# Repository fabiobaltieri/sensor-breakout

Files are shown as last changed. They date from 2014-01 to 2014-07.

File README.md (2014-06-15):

Sensor Breakout
===============

http://fabiobaltieri.com/2014/06/15/sensor-breakout/

This project is brekout board for prototyping wireless sensors.

Main features:
- ATMega88P microcontroller (can mount up to an ATMetga328)
- nRF24L01+ low power 2.4GHz radio
- On board Lithium battery charger and 3.3V regulator
- Dual mounting option for the USB port (micro B and A)
- Prototype area

License
-------

This program is free software: you can redistribute it and/or modify
it under the terms of the GNU General Public License as published by
the Free Software Foundation, either version 2 of the License, or
(at your option) any later version.

Contents
--------

    COPYING      text version of the GPL
    README       this file
    bootloader/  source directory for bootloader
    firmware/    source directory for main firmware
    hardware/    source directory for the hardware design

Firmware and Bootloader
-----------------------

Building requires an avr-gcc toolchain, in the firmware/ or bootloader/
directory, to build run:

    make

Flashing the firmware on the device requires avrdude and a compatible hardware
programmer. Default configuration is stored at the beginning of the Makefile.
To program with the default configuration, run:

    make flash

Fuses can be configured running:

    make fuses

To program the main firmware from the bootloader, use the command:

    make boot

Hardware
--------

All hardware files (schematic, layout and libraries) are in CadSoft Eagle
format.

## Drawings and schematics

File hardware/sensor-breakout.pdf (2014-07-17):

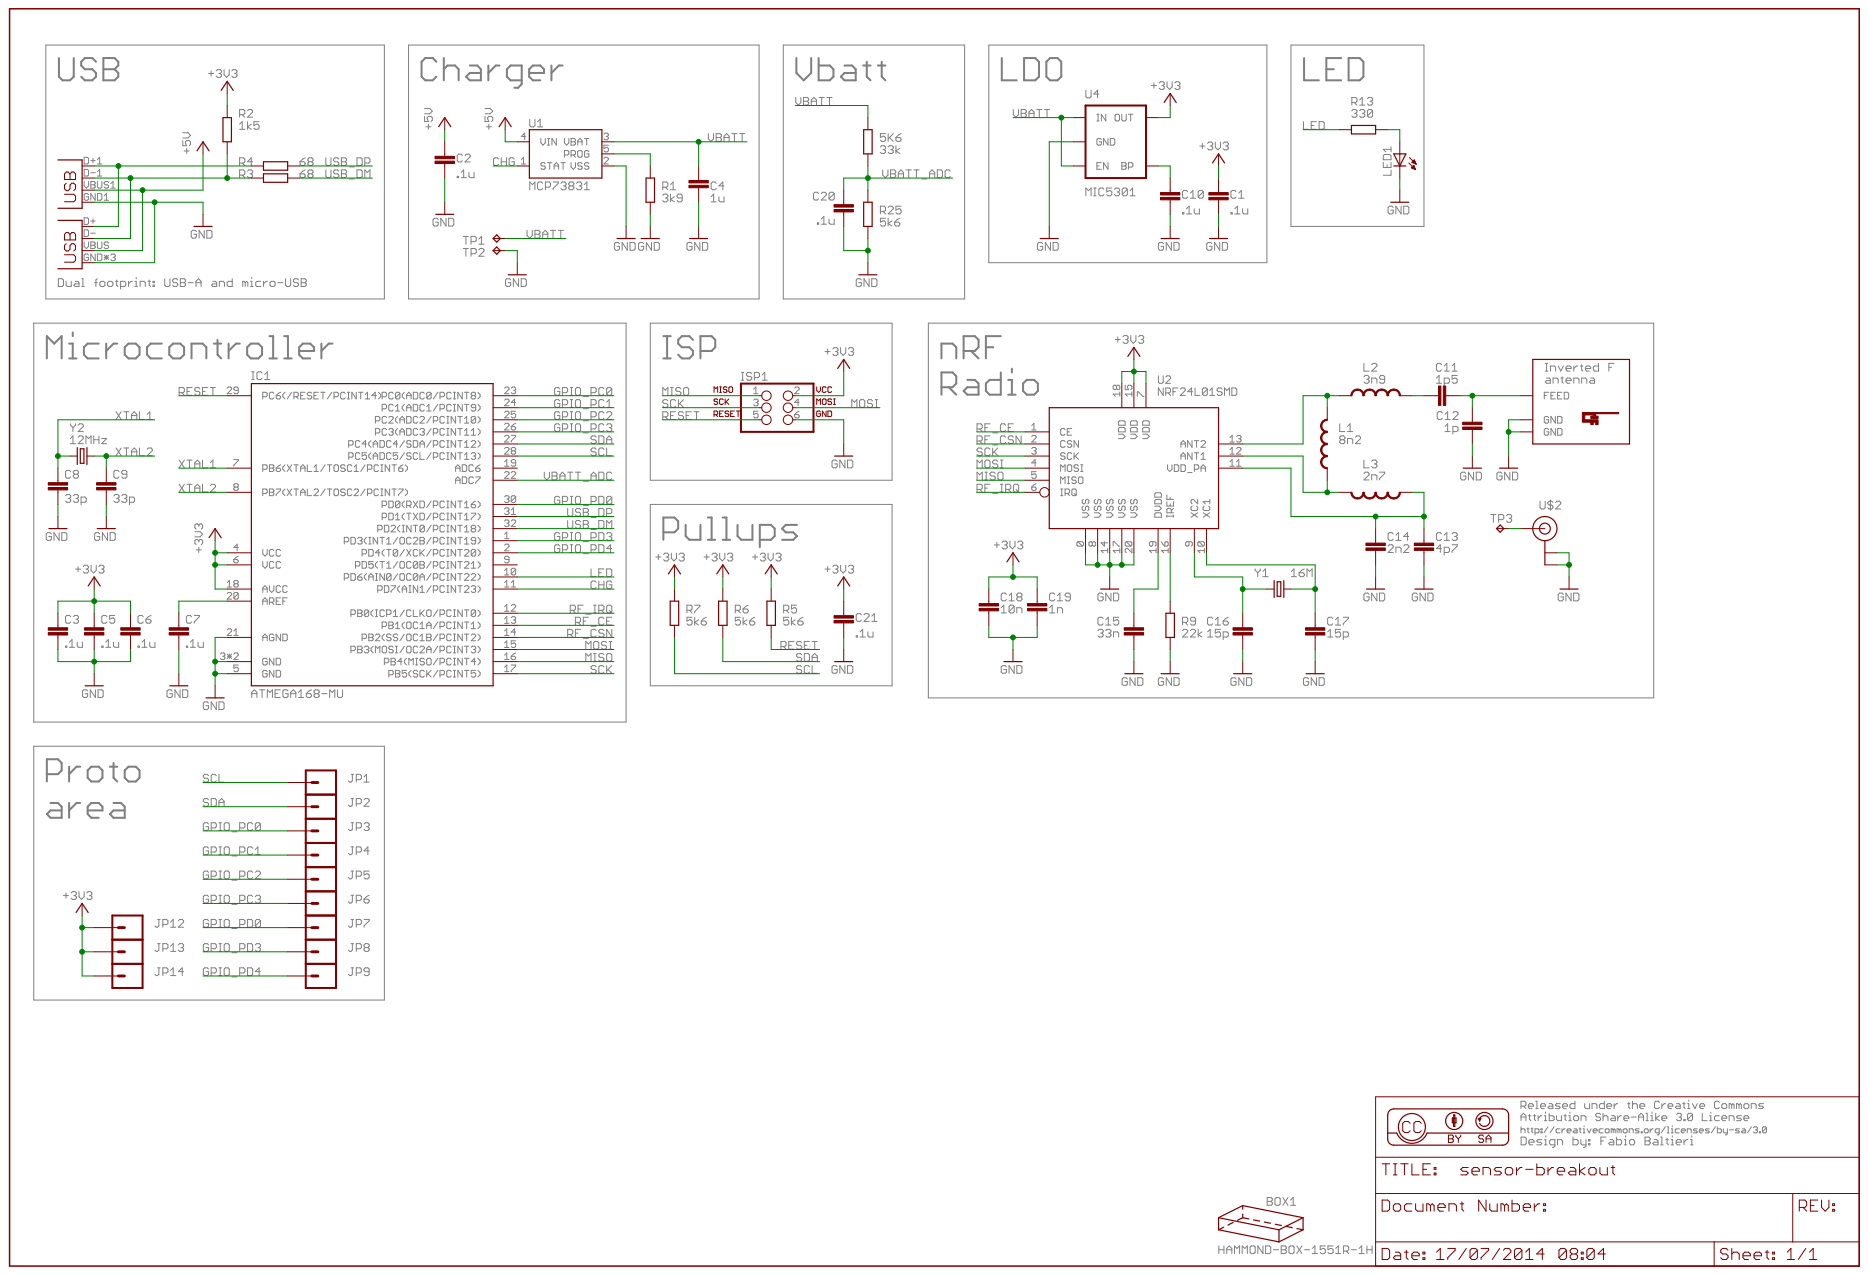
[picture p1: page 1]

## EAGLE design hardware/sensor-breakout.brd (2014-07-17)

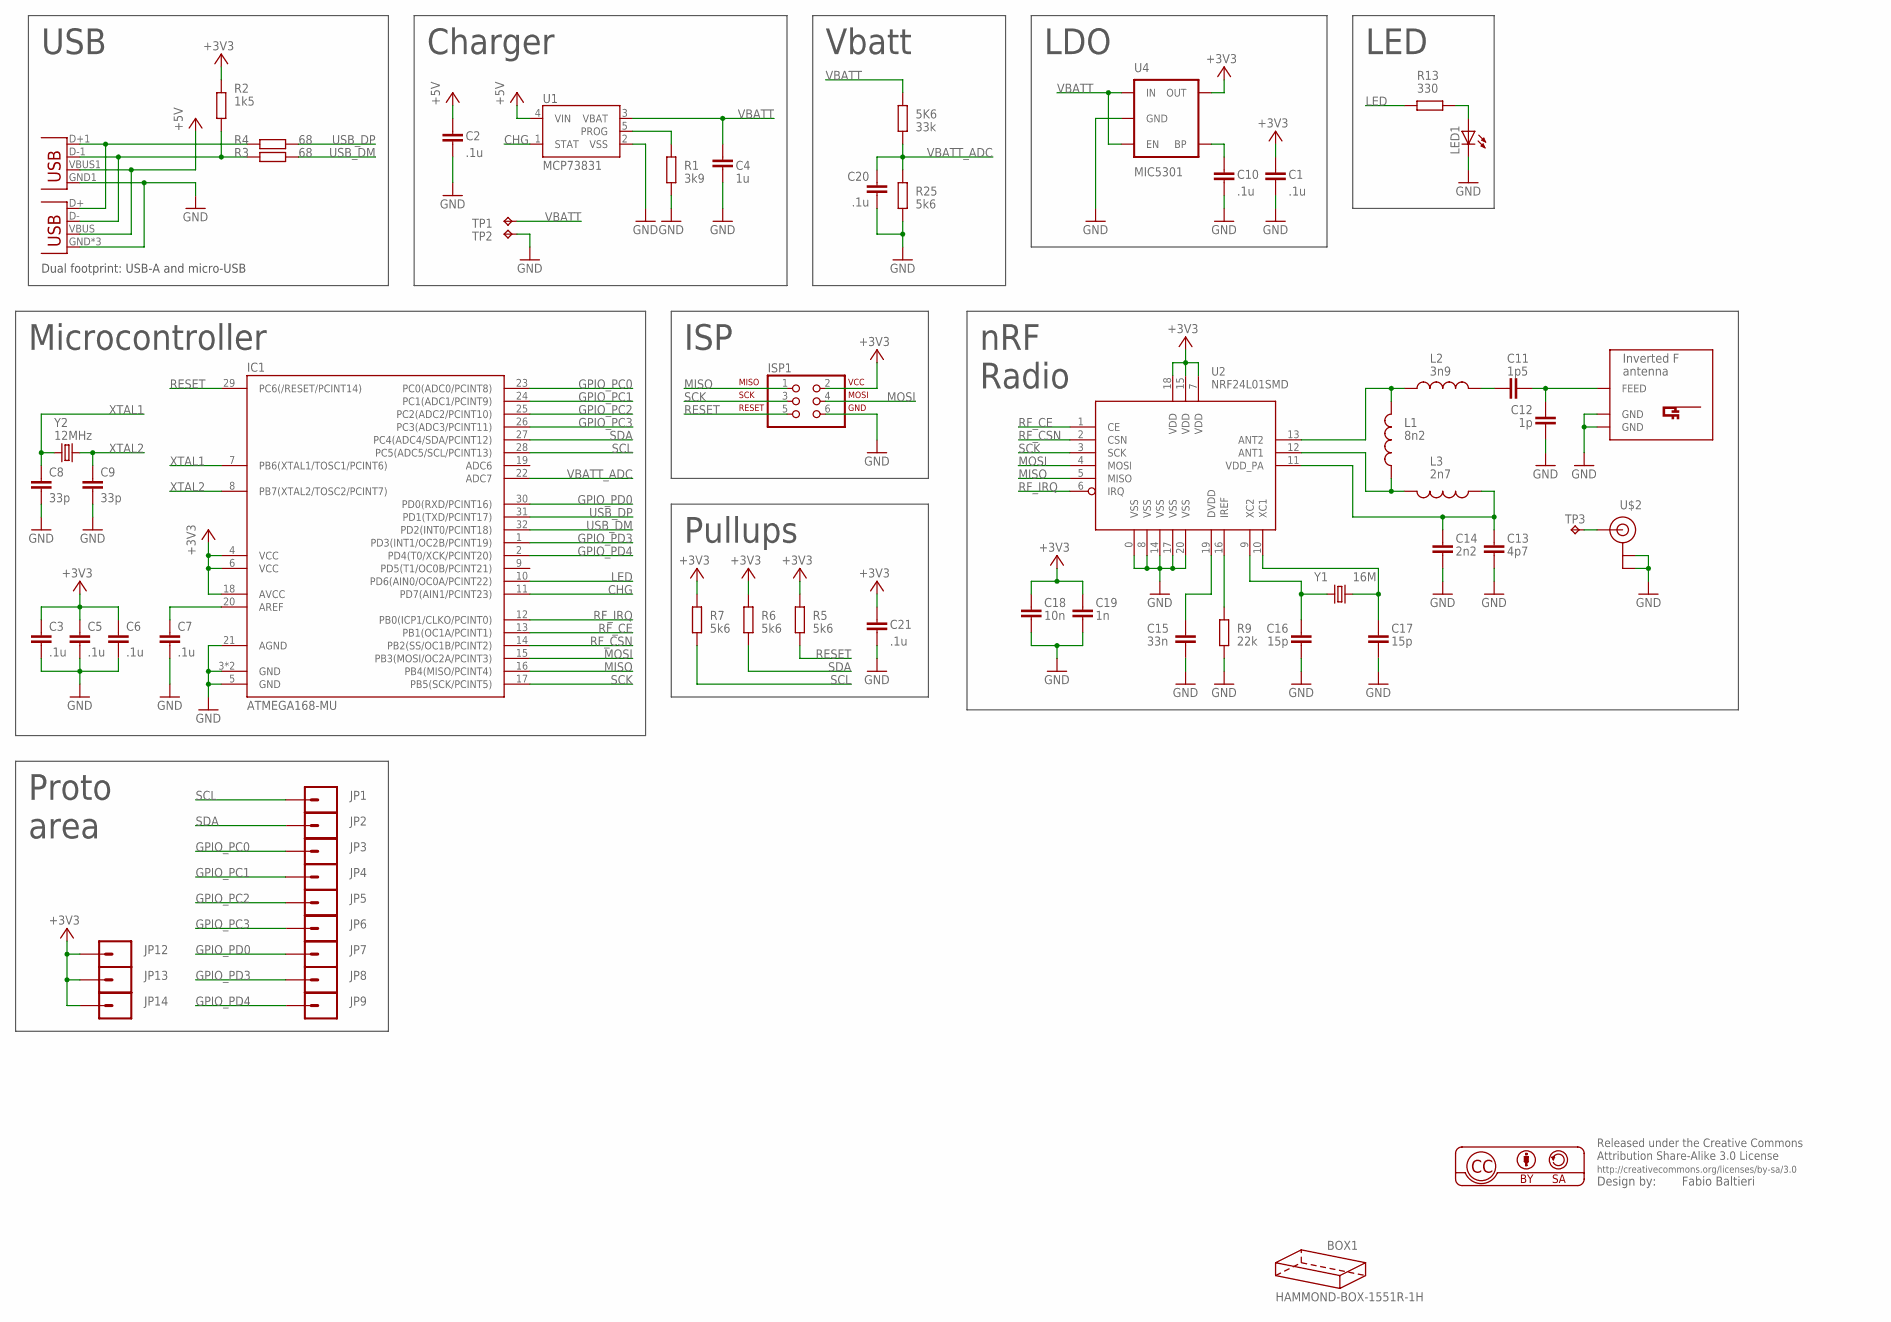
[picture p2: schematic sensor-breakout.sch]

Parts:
5K6: 33k; R0603
BOX1: HAMMOND-BOX-1551R-1H; 1551R-1HOLE
C1, C2, C3, C5, C6, C7, C10, C20, C21: .1u; C0603
C4: 1u; C0603
C8, C9: 33p; C0603
C11: 1p5; C0603
C12: 1p; C0603
C13: 4p7; C0603
C14: 2n2; C0603
C15: 33n; C0603
C16, C17: 15p; C0603
C18: 10n; C0603
C19: 1n; C0603
IC1: ATMEGA168-MU; MLF32-TH
ISP1: ISP-AVR910PTH; 2X03
JP1, JP2, JP3, JP4, JP5, JP6, JP7, JP8, JP9, JP12, JP13, JP14: M01NOSILK-KIT; 1X01NS-KIT
JP10: USB-MICROB
JP11: USBA-SMD-MALE; USB-A-SMT-MALE
L1: 8n2; 0603
L2: 3n9; 0603
L3: 2n7; 0603
LED1: LEDSML0805; SML0805
R1: 3k9; R0603
R2: 1k5; R0603
R3, R4: 68; R0603
R5, R6, R7, R25: 5k6; R0603
R9: 22k; R0603
R13: 330; R0603
TP1, TP2: TPTP12R; TP12R
TP3: TPTP08SQ; TP08SQ
U1: MCP73831; SOT23-5
U2: NRF24L01SMD; QFN20
U4: MIC5301; SOT23-5
U$1: INVERTED_F_ANTENNA-2; DN007-2
U$2: U.FL
Y1: 16M; CRYSTAL-SMD-5X3
Y2: 12MHz; CRYSTAL-SMD-5X3

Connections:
+3V3: C1.1, C3.1, C5.1, C6.1, C18.1, C19.1, C21.1, IC1.4 (VCC), IC1.6 (VCC), IC1.18 (AVCC), ISP1.2, JP12.1, JP13.1, JP14.1, R2.2, R5.1, R6.1, R7.1, U2.7 (VDD), U2.15 (VDD), U2.18 (VDD), U4.5 (OUT)
+5V: C2.1, JP10.VBUS, JP11.VBUS1 (VBUS), U1.4 (VIN)
CHG: IC1.11 (PD7(AIN1/PCINT23)), U1.1 (STAT)
GND: C1.2, C2.2, C3.2, C4.2, C5.2, C6.2, C7.2, C8.2, C9.2, C10.2, C12.2, C13.2, C14.2, C15.2, C16.2, C17.2, C18.2, C19.2, C20.2, C21.2, IC1.3 (GND), IC1.5 (GND), IC1.21 (AGND), IC1.TH (GND), ISP1.6, JP10.GND, JP10.MT1 (GND), JP10.MT2 (GND), JP11.GND1 (GND), LED1.C, R1.2, R9.2, R25.2, TP2.TP, U1.2 (VSS), U2.0 (VSS), U2.8 (VSS), U2.14 (VSS), U2.17 (VSS), U2.20 (VSS), U4.2 (GND), U$1.GND, U$1.GND@1 (GND), U$2.P$1 (GND), U$2.P$2 (GND)
GPIO_PC0: IC1.23 (PC0(ADC0/PCINT8)), JP3.1
GPIO_PC1: IC1.24 (PC1(ADC1/PCINT9)), JP4.1
GPIO_PC2: IC1.25 (PC2(ADC2/PCINT10)), JP5.1
GPIO_PC3: IC1.26 (PC3(ADC3/PCINT11)), JP6.1
GPIO_PD0: IC1.30 (PD0(RXD/PCINT16)), JP7.1
GPIO_PD3: IC1.1 (PD3(INT1/OC2B/PCINT19)), JP8.1
GPIO_PD4: IC1.2 (PD4(T0/XCK/PCINT20)), JP9.1
LED: IC1.10 (PD6(AIN0/OC0A/PCINT22)), R13.2
MISO: IC1.16 (PB4(MISO/PCINT4)), ISP1.1, U2.5 (MISO)
MOSI: IC1.15 (PB3(MOSI/OC2A/PCINT3)), ISP1.4, U2.4 (MOSI)
unnamed: JP10.D+, JP11.D+1 (D+), R4.2
unnamed: C7.1, IC1.20 (AREF)
unnamed: LED1.A, R13.1
unnamed: R1.1, U1.5 (PROG)
unnamed: L1.2, L3.2, U2.12 (ANT1)
unnamed: L1.1, L2.1, U2.13 (ANT2)
unnamed: JP10.D-, JP11.D-1 (D-), R2.1, R3.2
unnamed: C10.1, U4.4 (BP)
unnamed: C11.1, L2.2
unnamed: C11.2, C12.1, U$1.FEED
unnamed: C13.1, C14.1, L3.1, U2.11 (VDD_PA)
unnamed: C15.1, U2.19 (DVDD)
unnamed: R9.1, U2.16 (IREF)
unnamed: C17.1, U2.10 (XC1), Y1.3 (2)
unnamed: C16.1, U2.9 (XC2), Y1.1
unnamed: TP3.TP, U$2.P$3 (SIGNAL)
RESET: IC1.29 (PC6(/RESET/PCINT14)), ISP1.5, R5.2
RF_CE: IC1.13 (PB1(OC1A/PCINT1)), U2.1 (CE)
RF_CSN: IC1.14 (PB2(SS/OC1B/PCINT2)), U2.2 (CSN)
RF_IRQ: IC1.12 (PB0(ICP1/CLKO/PCINT0)), U2.6 (IRQ)
SCK: IC1.17 (PB5(SCK/PCINT5)), ISP1.3, U2.3 (SCK)
SCL: IC1.28 (PC5(ADC5/SCL/PCINT13)), JP1.1, R7.2
SDA: IC1.27 (PC4(ADC4/SDA/PCINT12)), JP2.1, R6.2
USB_DM: IC1.32 (PD2(INT0/PCINT18)), R3.1
USB_DP: IC1.31 (PD1(TXD/PCINT17)), R4.1
VBATT: 5K6.1, C4.1, TP1.TP, U1.3 (VBAT), U4.1 (IN), U4.3 (EN)
VBATT_ADC: 5K6.2, C20.1, IC1.22 (ADC7), R25.1
XTAL1: C8.1, IC1.7 (PB6(XTAL1/TOSC1/PCINT6)), Y2.1
XTAL2: C9.1, IC1.8 (PB7(XTAL2/TOSC2/PCINT7)), Y2.3 (2)

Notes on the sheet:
ISP
LED
nRF
Charger
Radio
LDO
Microcontroller
USB
Pullups
Vbatt
Dual footprint: USB-A and micro-USB
Proto area

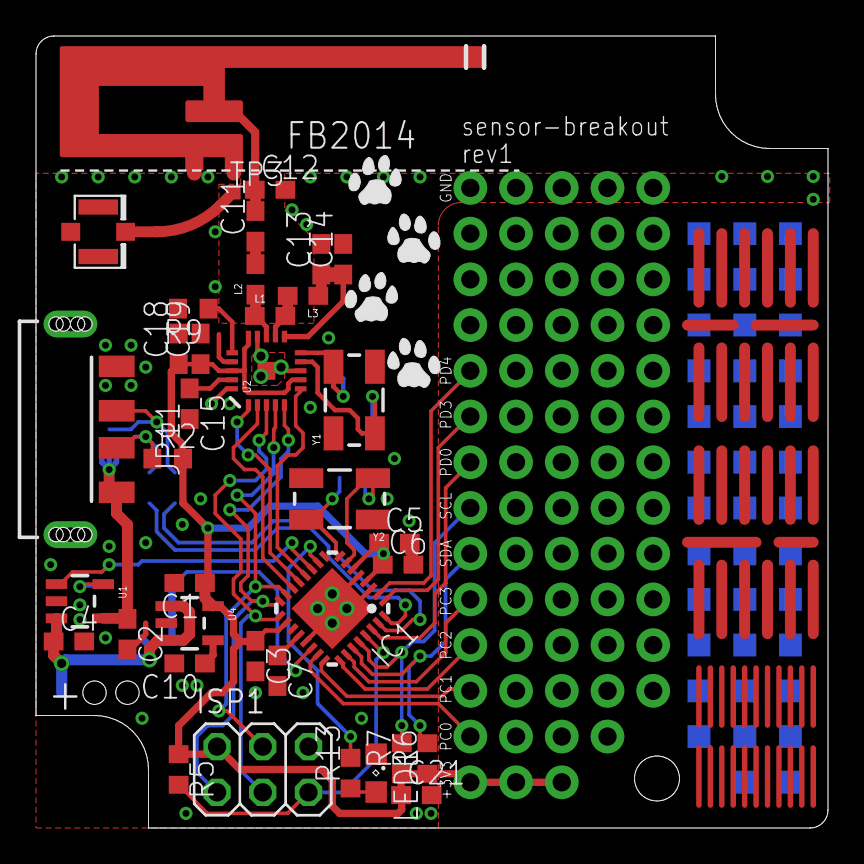
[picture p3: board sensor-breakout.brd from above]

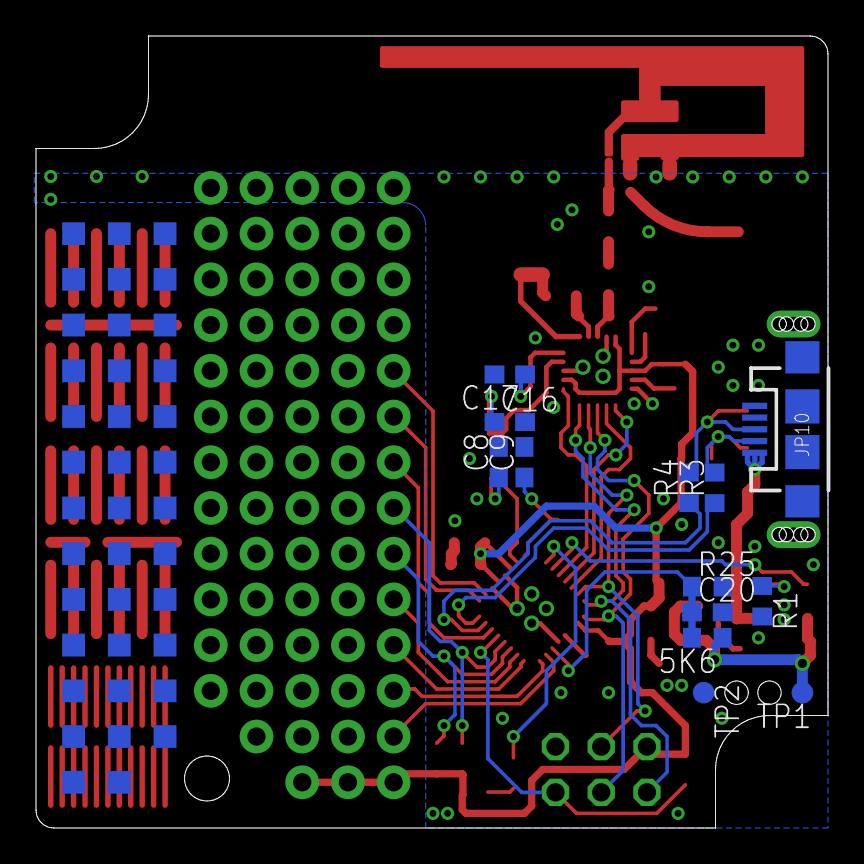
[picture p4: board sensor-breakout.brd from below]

Board: 2 copper layers, 44.0 x 44.0 mm, 67 parts (13 on the bottom side), 43 nets.

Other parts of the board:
U$3, U$5: CAT-R
U$4, U$6: CAT-L

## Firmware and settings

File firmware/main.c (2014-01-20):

/*
 * Copyright 2013 Fabio Baltieri (fabio.baltieri@gmail.com)
 *
 * This program is free software: you can redistribute it and/or modify
 * it under the terms of the GNU General Public License as published by
 * the Free Software Foundation, either version 3 of the License, or
 * (at your option) any later version.
 */

#include <avr/io.h>
#include <avr/sleep.h>
#include <avr/wdt.h>
#include <avr/interrupt.h>
#include <util/delay.h>
#include <string.h>

#include "board.h"
#include "id.h"
#include "adc.h"
#include "spi.h"
#include "nrf24l01p.h"
#include "nrf_frames.h"

#define div_round(a, b) (((a) + ((b)/2)) / (b))

static struct nrf_frame frm;

void reset_cpu(void)
{
	wdt_disable();

	wdt_enable(WDTO_15MS);

	for (;;);
}

static void hello(void)
{
	uint8_t i;

	for (i = 0; i < 8; i++) {
		led_toggle();
		_delay_ms(50);
	}
}

static void fill_frame(struct nrf_frame *frm)
{
	struct nrf_ambient *na = &frm->msg.ambient;
	uint32_t val;

	memset(frm, 0, sizeof(*frm));

	frm->board_id = get_board_id();
	frm->msg_id = NRF_MSG_ID_AMBIENT;
	frm->len = sizeof(*frm);
	frm->seq = 0;

	/* Vbatt */
	val = adc_get(ADC_VBATT, 1);
	val = div_round(val * ADC_VREF_mV * VBAT_H,
			ADC_VREF_BITS * VBAT_L);
	na->vbatt = val;

	if (is_charging())
		na->vbatt |= NRF_POWER_VBATT_CHARGING;
}

ISR(PCINT0_vect)
{
	nrf_poll();

	led_off();
}

ISR(WDT_vect)
{
	led_on();

	fill_frame(&frm);

	nrf_standby();
	nrf_tx((uint8_t *)&frm, sizeof(frm));
}

int __attribute__((noreturn)) main(void)
{
	led_init();
	spi_init();
	nrf_init();
	adc_init();
	chg_init();
	read_board_id();

	/* nRF interrupt */
	NRF_PCMSK |= _BV(NRF_PCINT);
	PCICR |= _BV(PCIE0);

	/* WDT as periodic interrupt */
	WDTCSR |= (1 << WDE) | (1 << WDCE);
	WDTCSR = (0 << WDCE) | (1 << WDIF) | (1 << WDIE) |
		(1 << WDP2) | (0 << WDP1) | (1 << WDP0);

	hello();
	led_off();

	sei();
	for (;;) {
		set_sleep_mode(SLEEP_MODE_PWR_DOWN);
		sleep_mode();
	}
}

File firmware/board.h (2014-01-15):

void reset_cpu(void);

/* LED */
#define LED_PORT	PORTD
#define LED_DDR		DDRD
#define LED		PD6

#define led_on()	LED_PORT |=  _BV(LED)
#define led_off()	LED_PORT &= ~_BV(LED)
#define led_toggle()	LED_PORT ^=  _BV(LED)

#define led_init()				\
	do {					\
		LED_DDR |= _BV(LED);		\
		LED_DDR |= _BV(LED);		\
	} while (0);

/* SPI */
#define SPI_DDR  DDRB
#define SPI_PORT PORTB
#define SPI_SS   PB2
#define SPI_SCK  PB5
#define SPI_MOSI PB3
#define SPI_MISO PB4

/* nRF24L01+ SPI */
#define NRF_DDR  DDRB
#define NRF_PORT PORTB
#define NRF_CS   SPI_SS
#define NRF_CE   PB1

#define nrf_cs_h() (NRF_PORT |=  _BV(NRF_CS))
#define nrf_cs_l() (NRF_PORT &= ~_BV(NRF_CS))
#define nrf_ce_h() (NRF_PORT |=  _BV(NRF_CE))
#define nrf_ce_l() (NRF_PORT &= ~_BV(NRF_CE))

#define NRF_PCMSK PCMSK0
#define NRF_PCINT PCINT0

/* Charger */
#define CHG_PORT        PORTD
#define CHG_PIN         PIND
#define CHG             PD7

#define chg_init()      do { CHG_PORT |= _BV(CHG); } while (0)
#define is_charging()   (!(CHG_PIN & _BV(CHG)))

/* ADC */
#define ADC_VREF_mV (1100 / 4)
#define ADC_VREF_BITS (1024 / 4)
#define ADC_VBATT 7

#define VBAT_L (56) /* divider low */
#define VBAT_H (330 + VBAT_L) /* divider high */

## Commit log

2013-11-24 hw: rc0
    [sensor-breakout.brd, sensor-breakout.sch]
2013-11-24 hw: rc1
    [sensor-breakout.brd, sensor-breakout.sch]
2013-11-24 hw: rc2
    [sensor-breakout.brd]
2013-12-15 hw: add pdf schematic
2014-01-01 bl: remove comment from fuse (avrdude gets confused)
2014-01-01 fw: add spi pins to board definitions
2014-01-01 fw: add spi and nrf files
2014-01-01 fw: add charger detection and battery voltage measurement
2014-01-01 fw: add adc code
2014-01-01 fw: add board id reding from eeprom
2014-01-02 hw: update values
    [sensor-breakout.brd, sensor-breakout.sch]
2014-01-14 fw: wait longer for adc to stabilize
    [adc.c]
2014-01-14 fw: nrf: put radio in powerdown after tx
2014-01-15 fw: call nrf_poll on radio interrupt
2014-01-20 fw: set sleep mod to power down
2014-05-05 hw: rev1, moved battery pads on bottom
    [sensor-breakout.brd]
2014-07-17 hw: fix ldo part number
    [sensor-breakout.brd, sensor-breakout.sch]

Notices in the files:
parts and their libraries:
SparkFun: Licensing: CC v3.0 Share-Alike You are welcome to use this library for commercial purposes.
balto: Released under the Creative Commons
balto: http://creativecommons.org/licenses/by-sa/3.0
